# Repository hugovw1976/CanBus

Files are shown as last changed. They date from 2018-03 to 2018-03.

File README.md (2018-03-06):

# CanBus
Wireless Control CanBus Electrical System for 1976 VW Bug.
NRF24L01 With ATmega328p Wireless control for car electrical system.
Transmitter run on ATmega 328p running on low power mode 1mhz: https://forum.mysensors.org/topic/3018/tutorial-how-to-burn-1mhz-8mhz-bootloader-using-arduino-ide-1-6-5-r5/2
Receiver run on Teensy 3.2 with SN65HVD230 transceiver, module communicate with front/rear/midle modules over CanBus
CanBus Modules run on Teensy 3.2 with SN65HVD230 transceiver.
Wiper control over LinBus (motor from BMW) LIN library from: https://github.com/gandrewstone/LIN/blob/master/LIN.ino
  
  Transmitter:







<a data-flickr-embed="true" data-context="true"  href="https://www.flickr.com/photos/r42bug/39444284152/in/dateposted/" title="20171224_134232">

Receiver:



Can modules:





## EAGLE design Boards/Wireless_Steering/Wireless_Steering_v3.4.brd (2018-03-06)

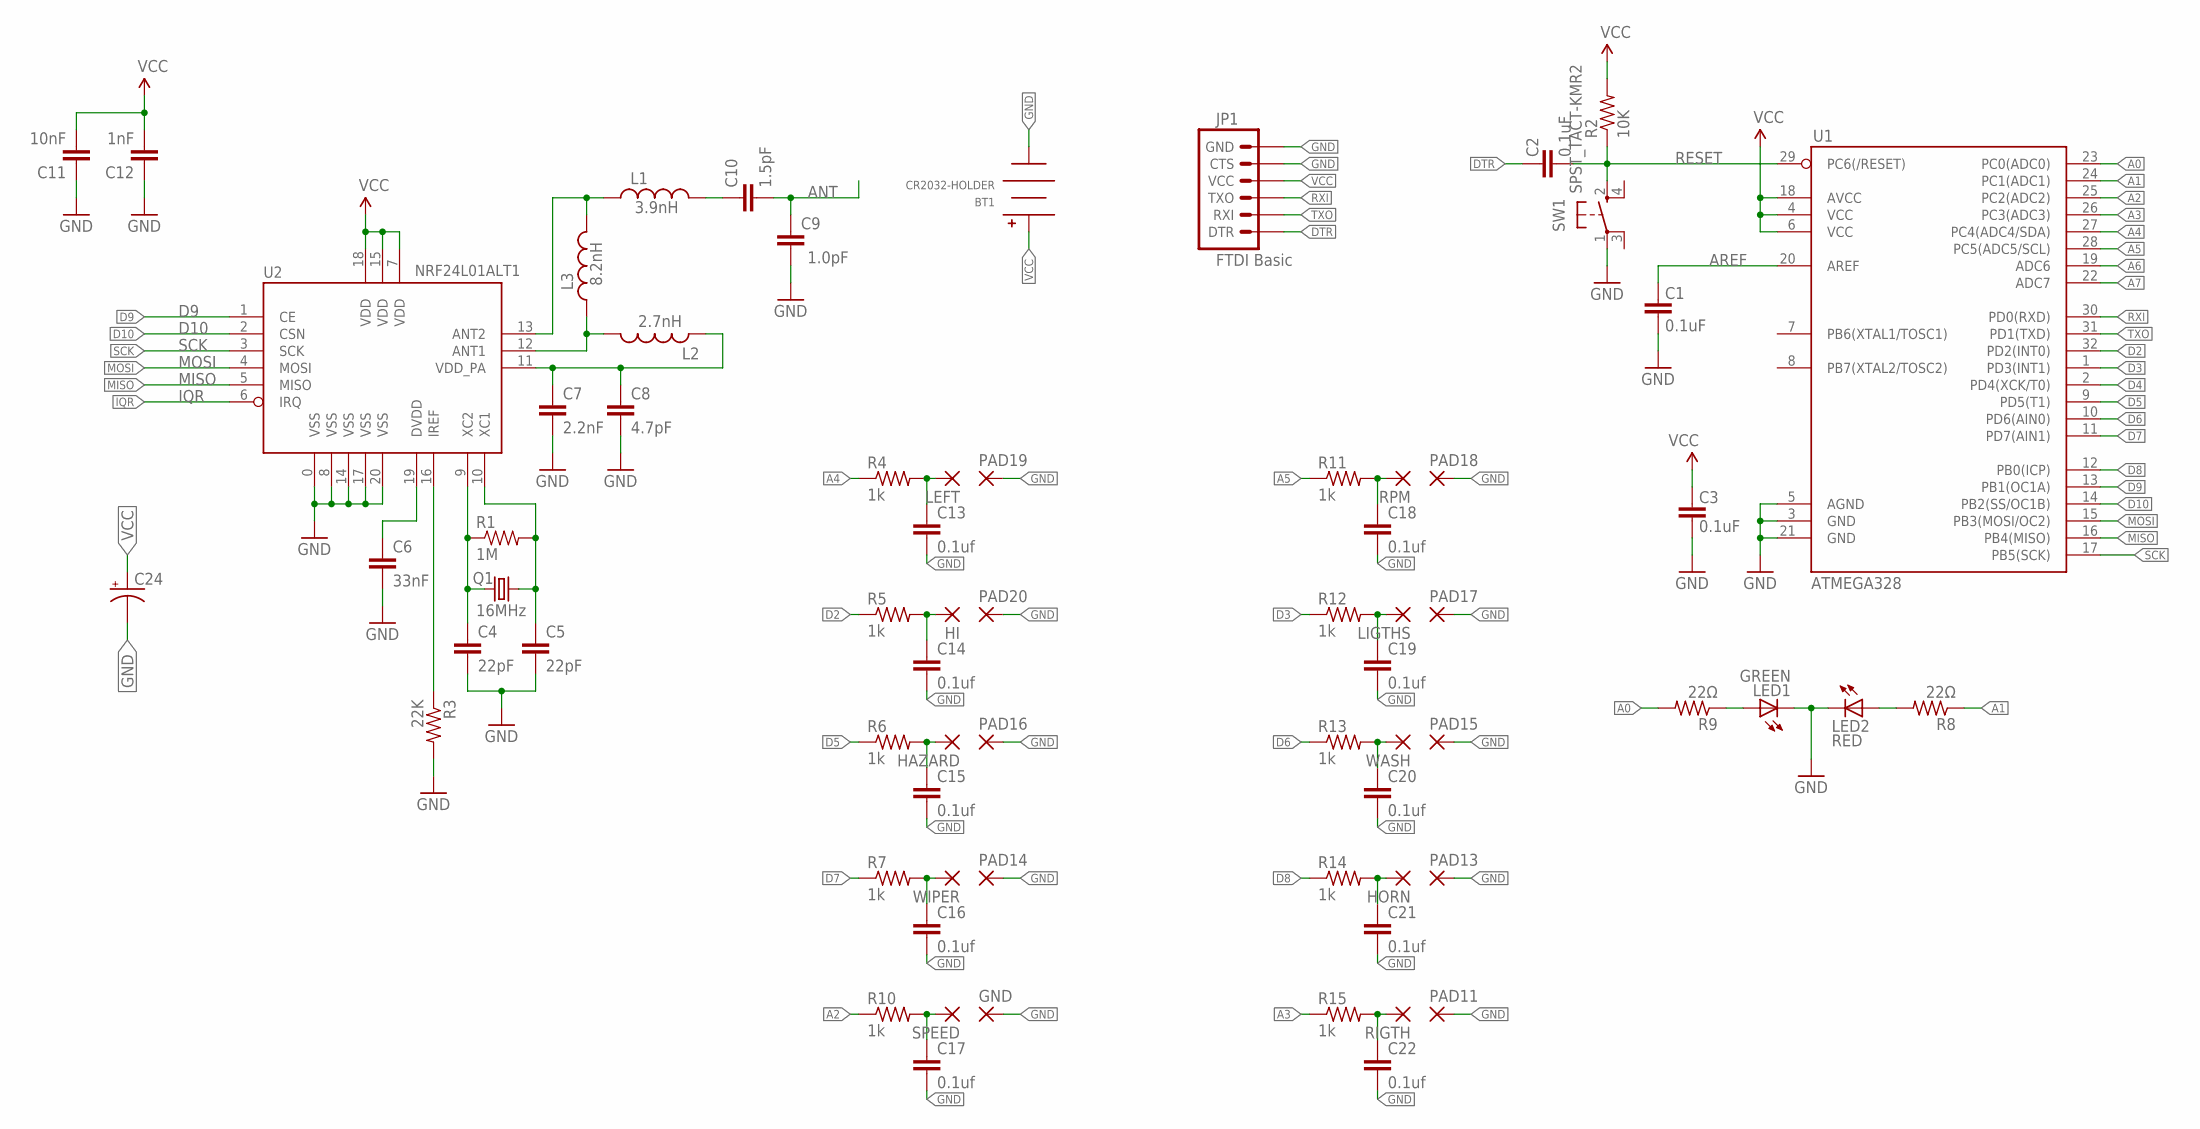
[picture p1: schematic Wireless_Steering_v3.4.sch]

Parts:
BT1: CR2032-HOLDER; CH28-2032LF
C1, C2, C3: 0.1uF; 0402-CAP
C4, C5: 22pF; 0402-CAP
C6: 33nF; 0402-CAP
C7: 2.2nF; 0402-CAP
C8: 4.7pF; 0402-CAP
C9: 1.0pF; 0402-CAP
C10: 1.5pF; 0402-CAP
C11: 10nF; 0402-CAP
C12: 1nF; 0402-CAP
C13, C14, C15, C16, C17, C18, C19, C20, C21, C22: 0.1uf; 0402-CAP
C24: CAP_POL1206; EIA3216
GND: SMD2; SMD1,27-2,54
HAZARD: SMD2; SMD1,27-2,54
HI: SMD2; SMD1,27-2,54
HORN: SMD2; SMD1,27-2,54
JP1: FTDI Basic; 1X06
L1: 3.9nH; C0402
L2: 2.7nH; C0402
L3: 8.2nH; C0402
LED1: GREEN; CHIP-LED0603
LED2: RED; CHIP-LED0603
LEFT: SMD2; SMD1,27-2,54
LIGTHS: SMD2; SMD1,27-2,54
PAD11, PAD13, PAD14, PAD15, PAD16, PAD17, PAD18, PAD19, PAD20: SMD2; SMD1,27-2,54
Q1: 16MHz; CRYSTAL-SMD-5X3
R1: 1M; 0402-RES
R2: 10K; 0402-RES
R3: 22K; 0402-RES
R4, R5, R6, R7, R10, R11, R12, R13, R14, R15: 1k; R0402
R8, R9: 22Ω; R0402
RIGTH: SMD2; SMD1,27-2,54
RPM: SMD2; SMD1,27-2,54
SPEED: SMD2; SMD1,27-2,54
SW1: SPST_TACT-KMR2; KMR2
U1: ATMEGA328; TQFP32-08
U2: NRF24L01ALT1; QFN20_ALT1
WASH: SMD2; SMD1,27-2,54
WIPER: SMD2; SMD1,27-2,54

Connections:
A0: R9.2, U1.23 (PC0(ADC0))
A1: R8.1, U1.24 (PC1(ADC1))
A2: R10.1, U1.25 (PC2(ADC2))
A3: R15.1, U1.26 (PC3(ADC3))
A4: R4.1, U1.27 (PC4(ADC4/SDA))
A5: R11.1, U1.28 (PC5(ADC5/SCL))
A6: U1.19 (ADC6)
A7: U1.22 (ADC7)
ANT: C9.2, C10.2
AREF: C1.2, U1.20 (AREF)
D2: R5.1, U1.32 (PD2(INT0))
D3: R12.1, U1.1 (PD3(INT1))
D4: U1.2 (PD4(XCK/T0))
D5: R6.1, U1.9 (PD5(T1))
D6: R13.1, U1.10 (PD6(AIN0))
D7: R7.1, U1.11 (PD7(AIN1))
D8: R14.1, U1.12 (PB0(ICP))
D9: U1.13 (PB1(OC1A)), U2.1 (CE)
D10: U1.14 (PB2(SS/OC1B)), U2.2 (CSN)
DTR: C2.2, JP1.1 (DTR)
GND: BT1.NEG, C1.1, C3.1, C4.2, C5.2, C6.2, C7.2, C8.2, C9.1, C11.1, C12.1, C13.2, C14.2, C15.2, C16.2, C17.2, C18.2, C19.2, C20.2, C21.2, C22.2, C24.C (-), GND.1, JP1.5 (CTS), JP1.6 (GND), LED1.C, LED2.C, PAD11.1, PAD13.1, PAD14.1, PAD15.1, PAD16.1, PAD17.1, PAD18.1, PAD19.1, PAD20.1, R3.2, SW1.1, U1.3 (GND), U1.5 (AGND), U1.21 (GND), U2.0 (VSS), U2.8 (VSS), U2.14 (VSS), U2.17 (VSS), U2.20 (VSS)
IQR: U2.6 (IRQ)
MISO: U1.16 (PB4(MISO)), U2.5 (MISO)
MOSI: U1.15 (PB3(MOSI/OC2)), U2.4 (MOSI)
unnamed: C4.1, Q1.1, R1.1, U2.9 (XC2)
unnamed: C5.1, Q1.3 (2), R1.2, U2.10 (XC1)
unnamed: L1.1, L3.2, U2.13 (ANT2)
unnamed: LED2.A, R8.2
unnamed: LED1.A, R9.1
unnamed: C7.1, C8.1, L2.1, U2.11 (VDD_PA)
unnamed: R3.1, U2.16 (IREF)
unnamed: C6.1, U2.19 (DVDD)
unnamed: L2.2, L3.1, U2.12 (ANT1)
unnamed: C10.1, L1.2
unnamed: C13.1, LEFT.1, R4.2
unnamed: C14.1, HI.1, R5.2
unnamed: C16.1, R7.2, WIPER.1
unnamed: C17.1, R10.2, SPEED.1
unnamed: C22.1, R15.2, RIGTH.1
unnamed: C21.1, HORN.1, R14.2
unnamed: C20.1, R13.2, WASH.1
unnamed: C19.1, LIGTHS.1, R12.2
unnamed: C18.1, R11.2, RPM.1
unnamed: C15.1, HAZARD.1, R6.2
RESET: C2.1, R2.1, SW1.2 (S), U1.29 (PC6(/RESET))
RXI: JP1.3 (TXO), U1.30 (PD0(RXD))
SCK: U1.17 (PB5(SCK)), U2.3 (SCK)
TXO: JP1.2 (RXI), U1.31 (PD1(TXD))
VCC: BT1.POS, C3.2, C11.2, C12.2, C24.A (+), JP1.4 (VCC), R2.2, U1.4 (VCC), U1.6 (VCC), U1.18 (AVCC), U2.7 (VDD), U2.15 (VDD), U2.18 (VDD)

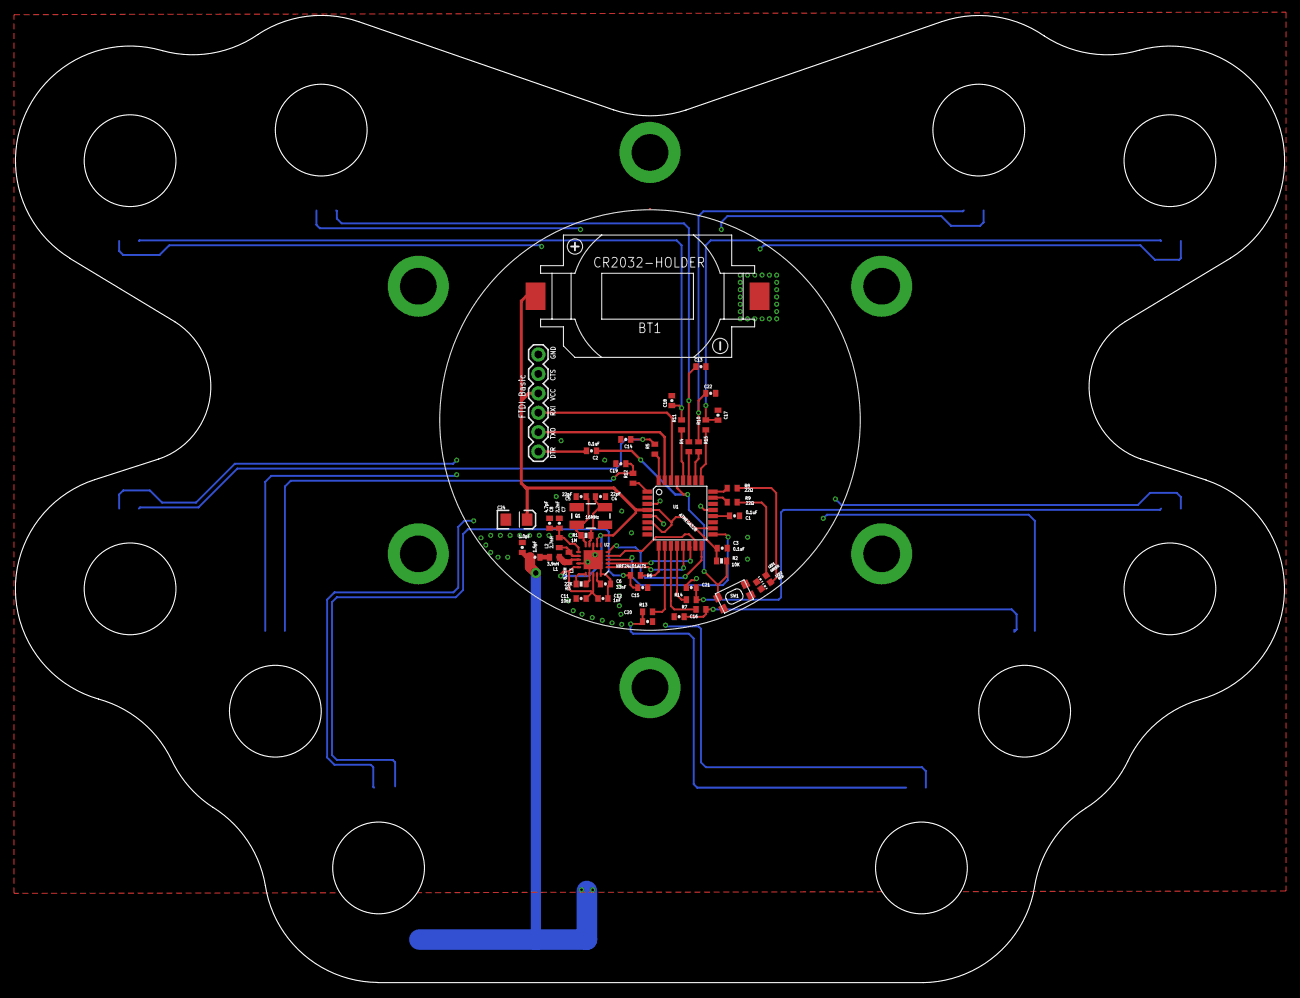
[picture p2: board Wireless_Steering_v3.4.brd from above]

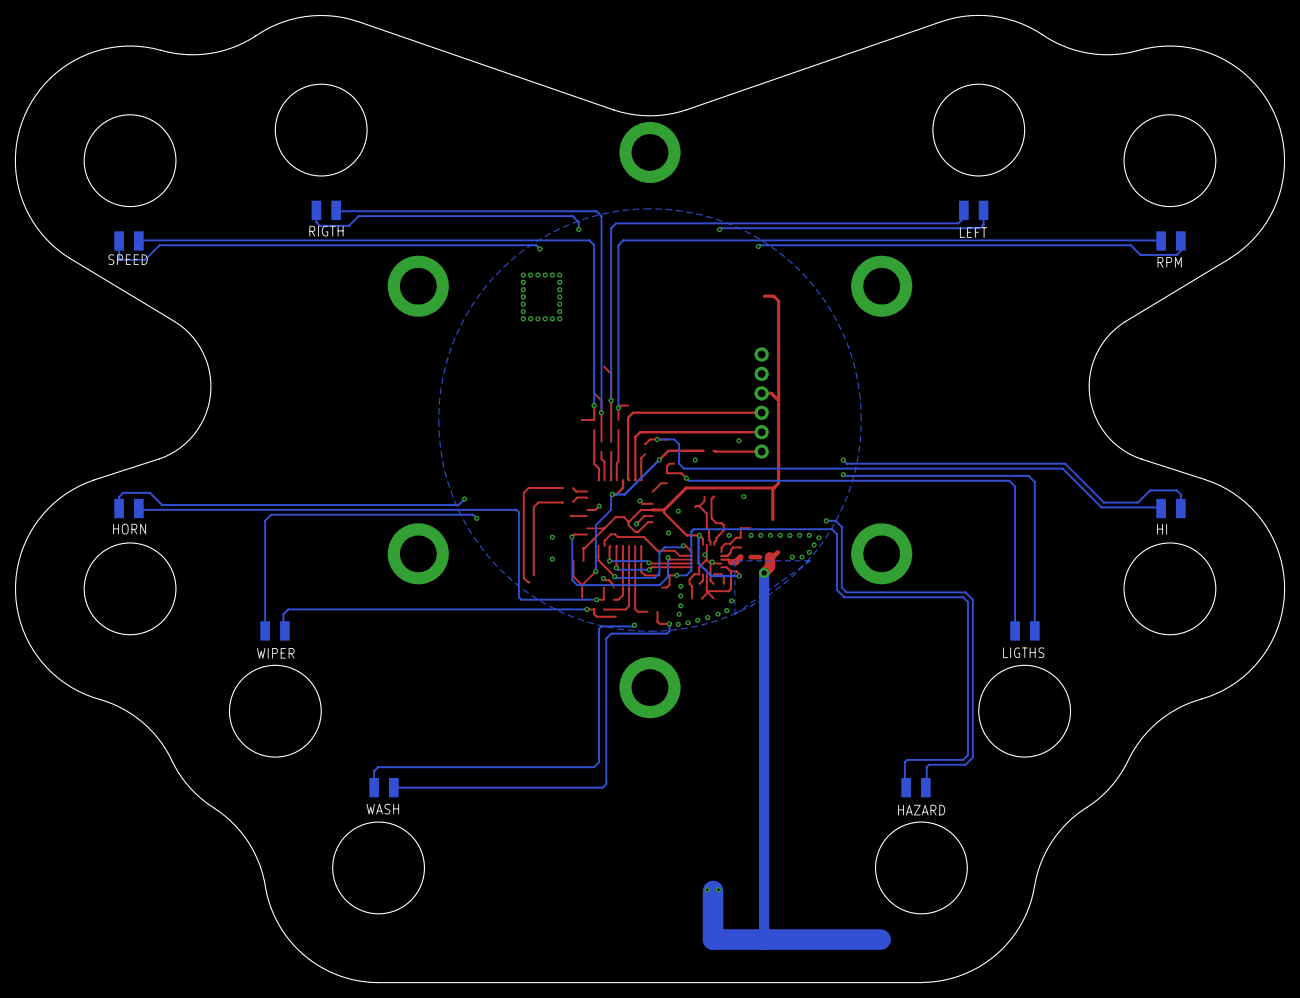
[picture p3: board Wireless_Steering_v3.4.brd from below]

Board: 2 copper layers, 166.0 x 126.5 mm, 69 parts (20 on the bottom side), 45 nets.

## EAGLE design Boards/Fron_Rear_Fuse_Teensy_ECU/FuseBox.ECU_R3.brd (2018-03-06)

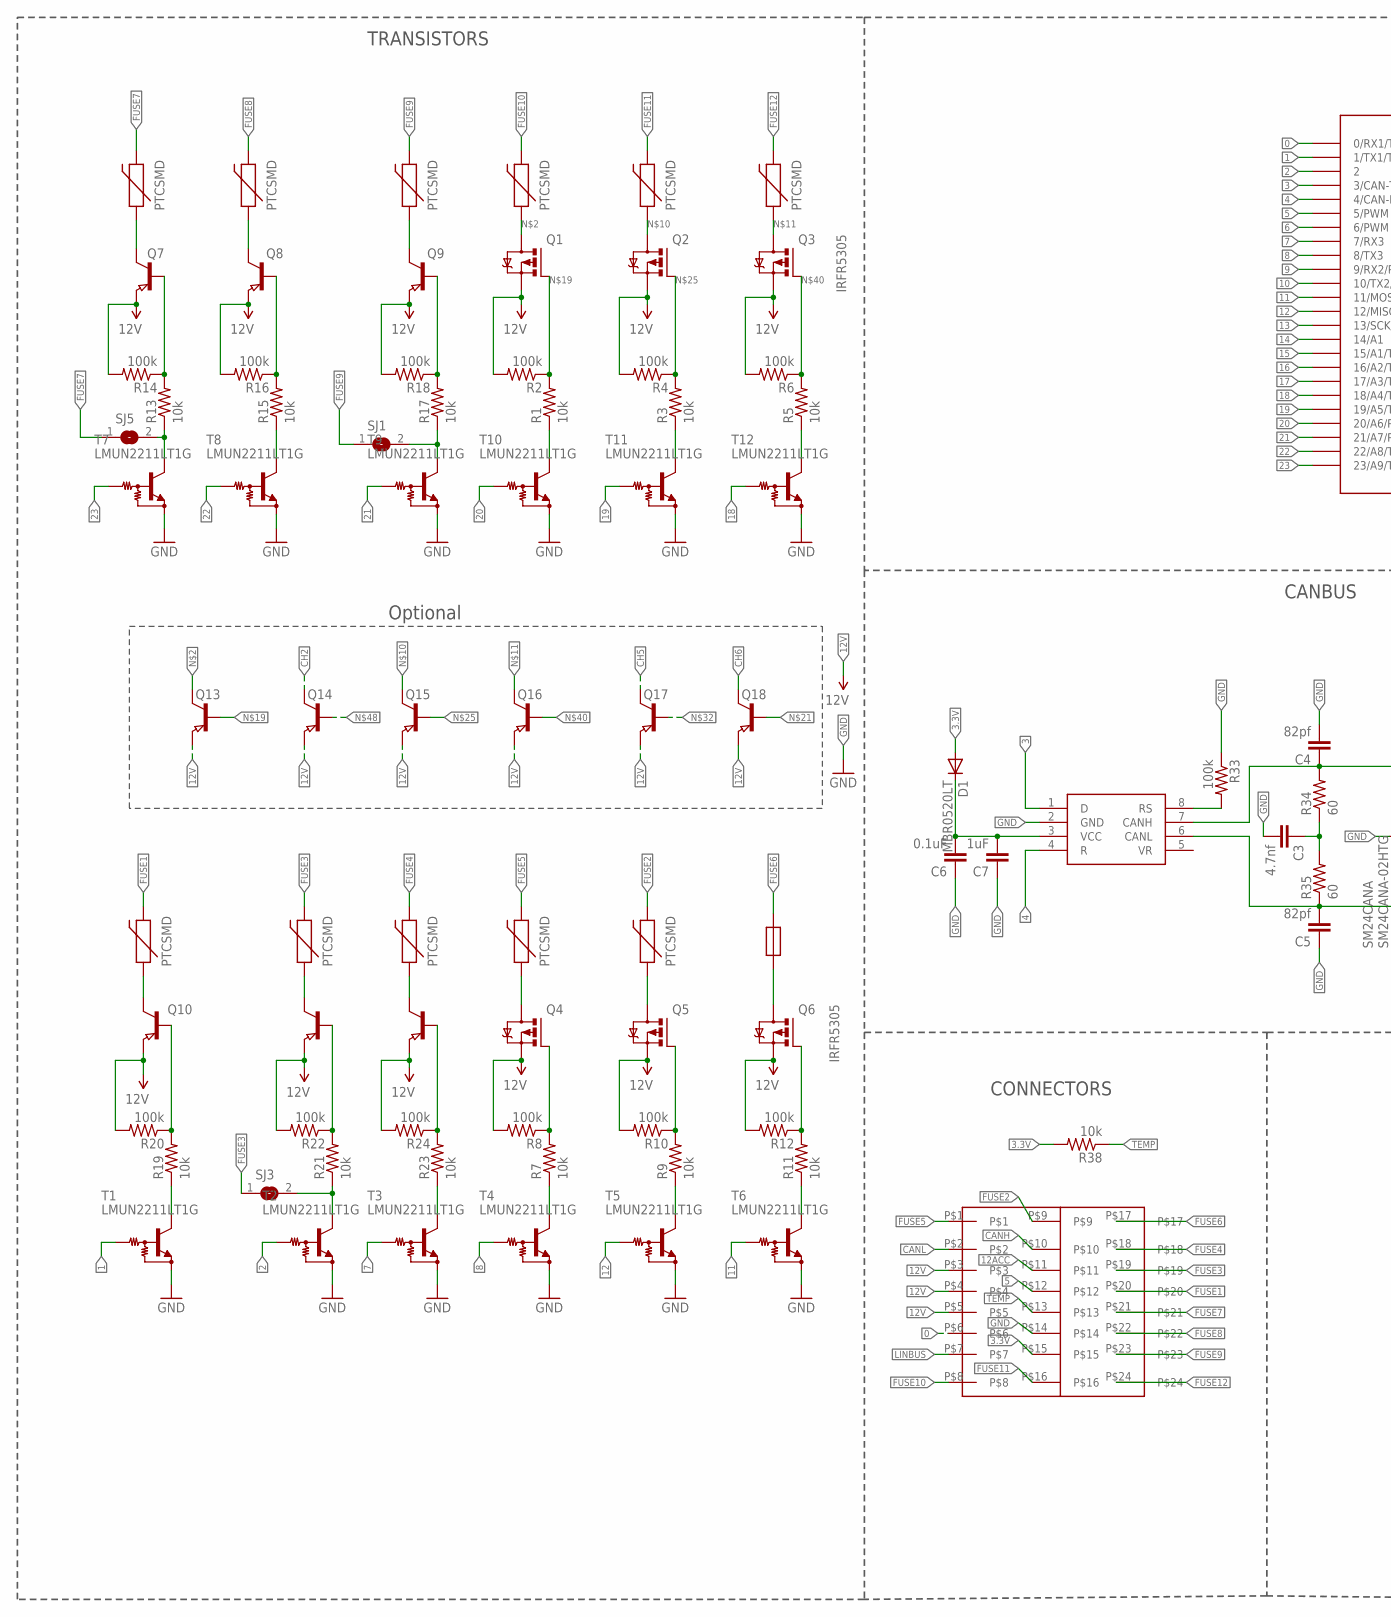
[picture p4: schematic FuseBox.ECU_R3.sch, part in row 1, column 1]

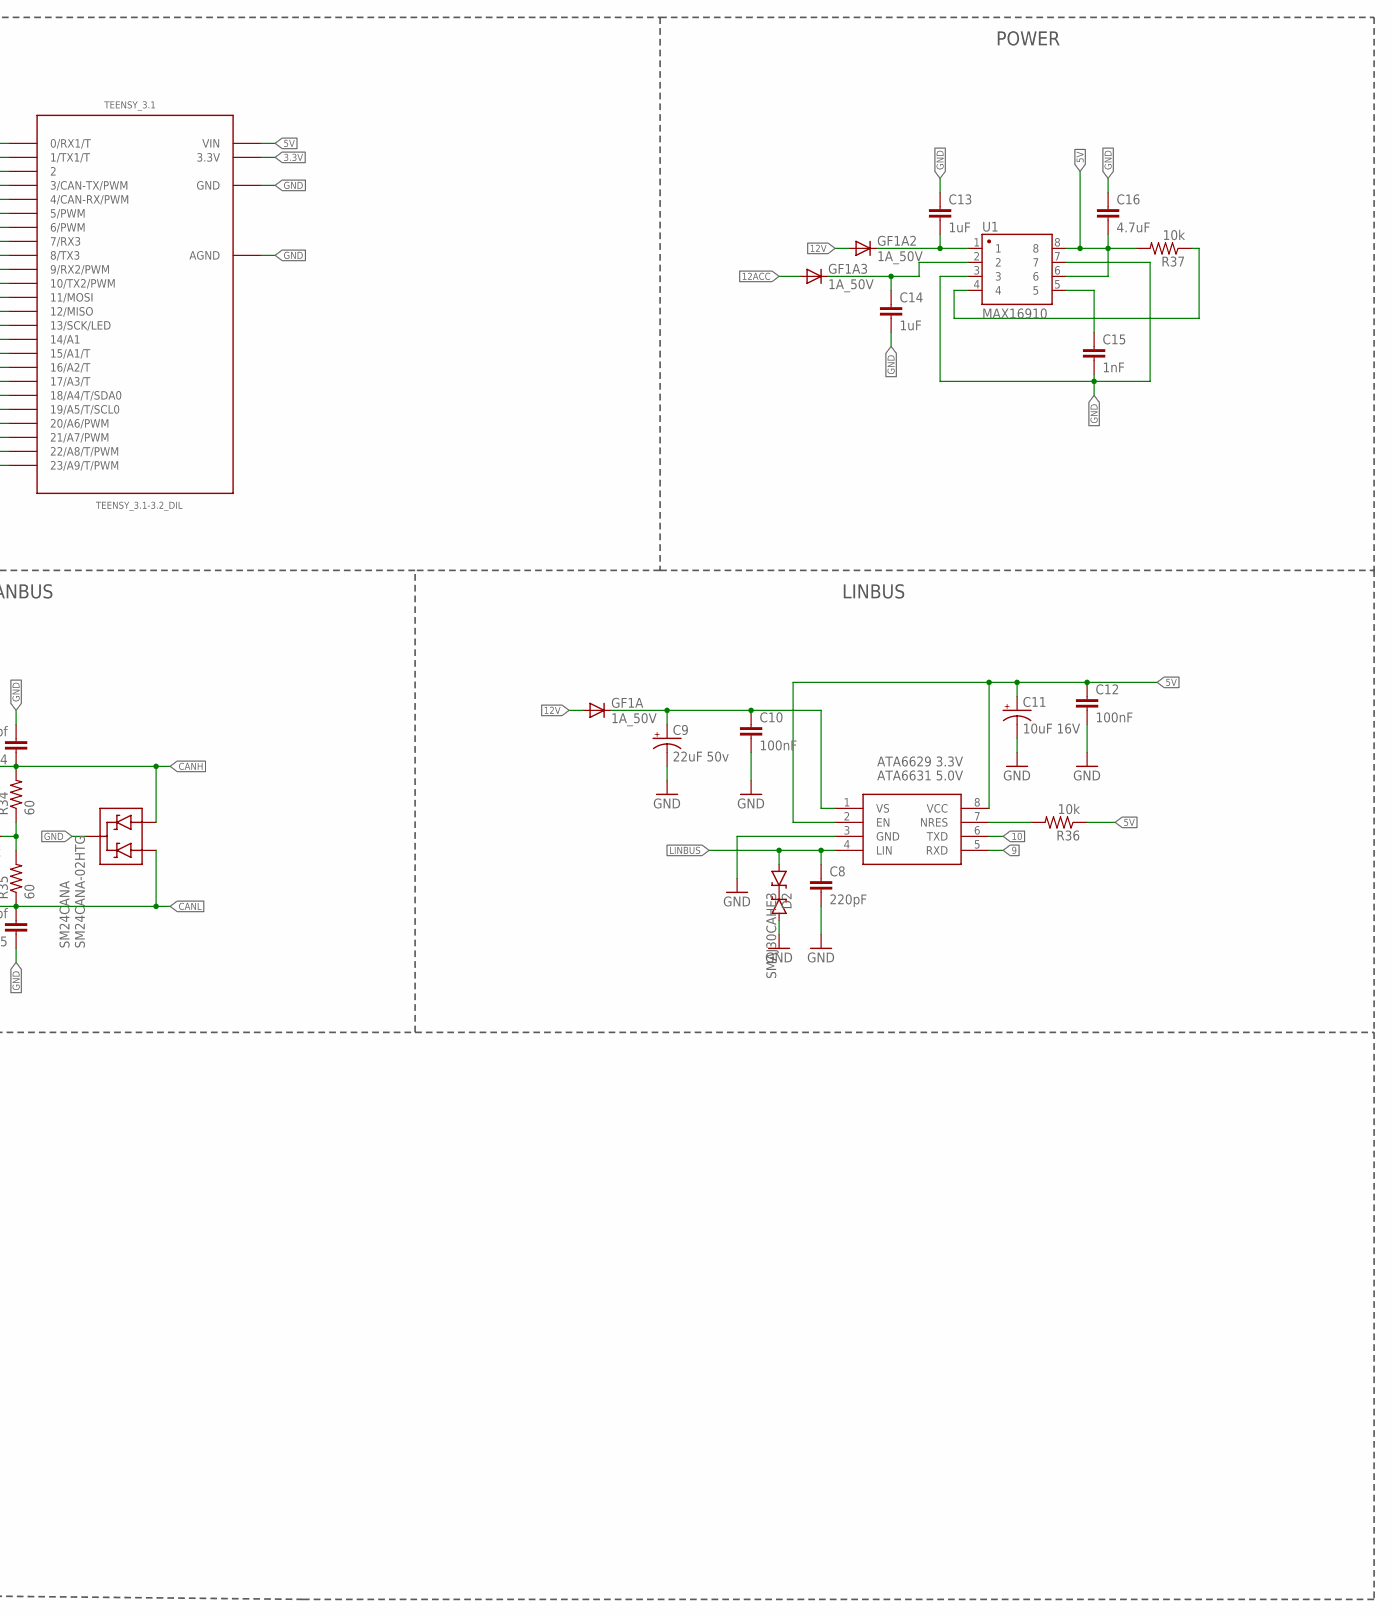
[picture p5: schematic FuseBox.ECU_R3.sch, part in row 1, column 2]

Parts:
ATA6631: ATA6631; S08
C3: 4.7nf; 0603-CAP
C4, C5: 82pf; 0603-CAP
C6: 0.1uF; 0603-CAP
C7: 1uF; 0603-CAP
C8: 220pF; 0603-CAP
C9: 22uF 50v; PANASONIC_D
C10, C12: 100nF; 0603-CAP
C11: 10uF 16V; EIA3216
C13, C14: 1uF; 0805
C15: 1nF; 0805
C16: 4.7uF; 0805
D1: MBR0520LT; SOD123
D2: SMAJ30CAHE3; SMA-DIODE
F1, F2, F3, F4, F5, F6, F7, F8, F9, F10, F11: PTCSMD; PTC-1206
GF1A, GF1A2, GF1A3: 1A_50V; DO-214AC
Q1, Q2, Q3, Q4, Q5, Q6: IRFR5305; D-PAK_TO252AA
Q7, Q8, Q9, Q10, Q11, Q12, Q13, Q14, Q15, Q16, Q17, Q18: PNP-TRANSISTOR_SOT23; SOT23
R1, R3, R5, R7, R9, R11, R13, R15, R17, R19, R21, R23, R38: 10k; R0402
R2, R4, R6, R8, R10, R12, R14, R16, R18, R20, R22, R24, R33: 100k; R0402
R34, R35: 60; R0402
R36, R37: 10k; 0603-RES
SJ1, SJ3, SJ5: SJ
SM24CANA: SM24CANA-02HTG; SOT23-3
T1, T2, T3, T4, T5, T6, T7, T8, T9, T10, T11, T12: LMUN2211LT1G; SOT23
TEENSY_3.1: TEENSY_3.1-3.2_DIL; TEENSY_3.0-3.2&LC_DIL
U1: MAX16910; SO08
U$2: RESETTABLE_1210; 1210
U$3: HCCPHPE24BKA90F
VP230: UP230; SO08

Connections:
0: TEENSY_3.1.0 (0/RX1/T), U$3.P$6
1: T1.1 (B), TEENSY_3.1.1 (1/TX1/T)
2: T2.1 (B), TEENSY_3.1.2
3: TEENSY_3.1.3 (3/CAN-TX/PWM), VP230.1 (D)
3.3V: D1.A, R38.2, TEENSY_3.1.3.3V, U$3.P$15
4: TEENSY_3.1.4 (4/CAN-RX/PWM), VP230.4 (R)
5: TEENSY_3.1.5 (5/PWM), U$3.P$12
5V: ATA6631.2 (EN), ATA6631.8 (VCC), C11.A (+), C12.1, C16.2, R36.1, R37.2, TEENSY_3.1.VIN, U1.6, U1.8
6: TEENSY_3.1.6 (6/PWM)
7: T3.1 (B), TEENSY_3.1.7 (7/RX3)
8: T4.1 (B), TEENSY_3.1.8 (8/TX3)
9: ATA6631.5 (RXD), TEENSY_3.1.9 (9/RX2/PWM)
10: ATA6631.6 (TXD), TEENSY_3.1.10 (10/TX2/PWM)
11: T6.1 (B), TEENSY_3.1.11 (11/MOSI)
12: T5.1 (B), TEENSY_3.1.12 (12/MISO)
12ACC: GF1A3.A, U$3.P$11
12V: GF1A.A, GF1A2.A, Q1.3 (S), Q2.3 (S), Q3.3 (S), Q4.3 (S), Q5.3 (S), Q6.3 (S), Q7.2 (E), Q8.2 (E), Q9.2 (E), Q10.2 (E), Q11.2 (E), Q12.2 (E), Q13.2 (E), Q14.2 (E), Q15.2 (E), Q16.2 (E), Q17.2 (E), Q18.2 (E), R2.2, R4.2, R6.2, R8.2, R10.2, R12.2, R14.2, R16.2, R18.2, R20.2, R22.2, R24.2, U$3.P$3, U$3.P$4, U$3.P$5
13: TEENSY_3.1.13 (13/SCK/LED)
14: TEENSY_3.1.14/A0 (14/A1)
15: TEENSY_3.1.15/A1 (15/A1/T)
16: TEENSY_3.1.16/A2 (16/A2/T)
17: TEENSY_3.1.17/A3 (17/A3/T)
18: T12.1 (B), TEENSY_3.1.18/A4 (18/A4/T/SDA0)
19: T11.1 (B), TEENSY_3.1.19/A5 (19/A5/T/SCL0)
20: T10.1 (B), TEENSY_3.1.20/A6 (20/A6/PWM)
21: T9.1 (B), TEENSY_3.1.21/A7 (21/A7/PWM)
22: T8.1 (B), TEENSY_3.1.22/A8 (22/A8/T/PWM)
23: T7.1 (B), TEENSY_3.1.23/A9 (23/A9/T/PWM)
CANH: C4.1, R34.2, SM24CANA.2 (A2), U$3.P$10, VP230.7 (CANH)
CANL: C5.2, R35.1, SM24CANA.1 (A1), U$3.P$2, VP230.6 (CANL)
CH2: F1.1, Q5.4 (D), Q14.3 (C)
CH5: F2.1, Q4.4 (D), Q17.3 (C)
CH6: Q6.4 (D), Q18.3 (C), U$2.P$1
CH7: F6.1, Q7.3 (C)
CH8: F7.1, Q8.3 (C)
CH9: F8.1, Q9.3 (C)
FUSE1: F5.2, U$3.P$20
FUSE2: F1.2, U$3.P$9
FUSE3: F4.2, SJ3.1, U$3.P$19
FUSE4: F3.2, U$3.P$18
FUSE5: F2.2, U$3.P$1
FUSE6: U$2.P$2, U$3.P$17
FUSE7: F6.2, SJ5.1, U$3.P$21
FUSE8: F7.2, U$3.P$22
FUSE9: F8.2, SJ1.1, U$3.P$23
FUSE10: F9.2, U$3.P$8
FUSE11: F10.2, U$3.P$16
FUSE12: F11.2, U$3.P$24
GND: ATA6631.3 (GND), C3.2, C4.2, C5.1, C6.1, C7.1, C8.2, C9.-, C10.2, C11.C (-), C12.2, C13.1, C14.2, C15.2, C16.1, D2.A, R33.1, SM24CANA.3 (C), T1.2 (E), T2.2 (E), T3.2 (E), T4.2 (E), T5.2 (E), T6.2 (E), T7.2 (E), T8.2 (E), T9.2 (E), T10.2 (E), T11.2 (E), T12.2 (E), TEENSY_3.1.AGND, TEENSY_3.1.GND, U1.3, U1.7, U$3.P$14, VP230.2 (GND)
LINBUS: ATA6631.4 (LIN), C8.1, D2.C (A1), U$3.P$7
unnamed: C6.2, C7.2, D1.C, VP230.3 (VCC)
unnamed: F9.1, Q1.4 (D), Q13.3 (C)
unnamed: R15.1, T8.3 (C)
unnamed: Q8.1 (B), R15.2, R16.1
unnamed: R13.1, SJ5.2, T7.3 (C)
unnamed: Q7.1 (B), R13.2, R14.1
unnamed: C13.2, GF1A2.C, U1.1
unnamed: R17.1, SJ1.2, T9.3 (C)
unnamed: F10.1, Q2.4 (D), Q15.3 (C)
unnamed: F11.1, Q3.4 (D), Q16.3 (C)
unnamed: C14.1, GF1A3.C, U1.2
unnamed: Q9.1 (B), R17.2, R18.1
unnamed: R1.1, T10.3 (C)
unnamed: Q1.1 (G), Q13.1 (B), R1.2, R2.1
unnamed: R11.1, T6.3 (C)
unnamed: Q6.1 (G), Q18.1 (B), R11.2, R12.1
unnamed: F5.1, Q10.3 (C)
unnamed: F4.1, Q11.3 (C)
unnamed: R3.1, T11.3 (C)
unnamed: Q2.1 (G), Q15.1 (B), R3.2, R4.1
unnamed: F3.1, Q12.3 (C)
unnamed: R23.1, T3.3 (C)
unnamed: Q12.1 (B), R23.2, R24.1
unnamed: R37.1, U1.4
unnamed: R7.1, T4.3 (C)
unnamed: Q4.1 (G), Q17.1 (B), R7.2, R8.1
unnamed: C15.1, U1.5
unnamed: R5.1, T12.3 (C)
unnamed: Q3.1 (G), Q16.1 (B), R5.2, R6.1
unnamed: R21.1, SJ3.2, T2.3 (C)
unnamed: Q11.1 (B), R21.2, R22.1
unnamed: R19.1, T1.3 (C)
unnamed: Q10.1 (B), R19.2, R20.1
unnamed: R9.1, T5.3 (C)
unnamed: Q5.1 (G), Q14.1 (B), R9.2, R10.1
unnamed: R33.2, VP230.8 (RS)
unnamed: ATA6631.1 (VS), C9.+, C10.1, GF1A.C
unnamed: ATA6631.7 (NRES), R36.2
unnamed: C3.1, R34.1, R35.2
TEMP: R38.1, U$3.P$13

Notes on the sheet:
ATA6631 5.0V
ATA6629 3.3V
Optional
TRANSISTORS
POWER
CANBUS
LINBUS
CONNECTORS

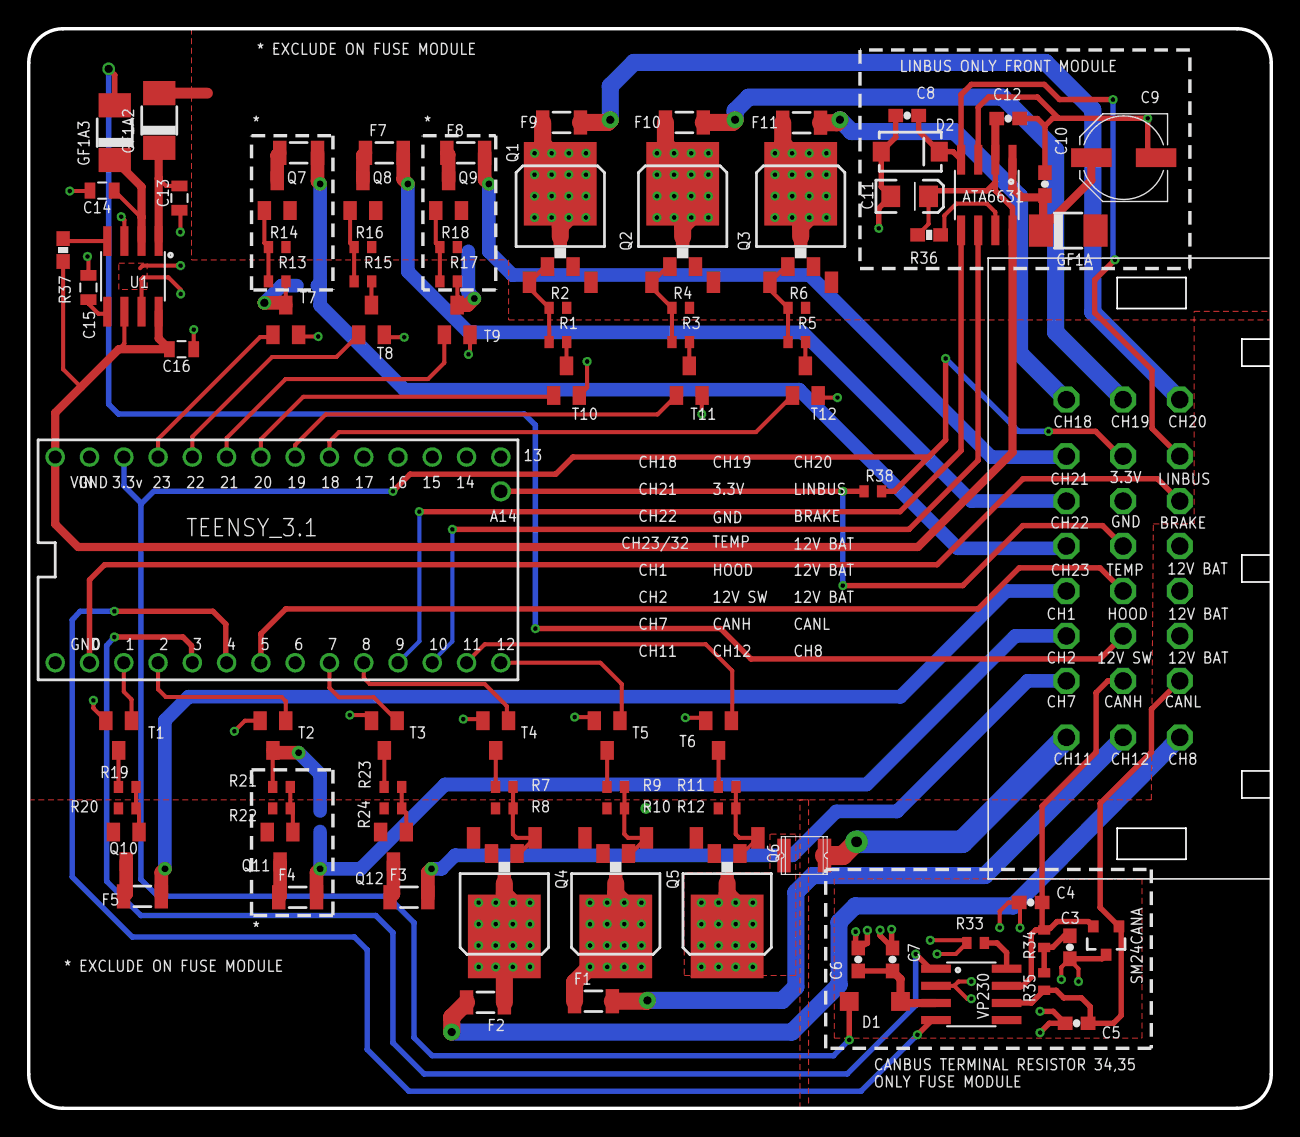
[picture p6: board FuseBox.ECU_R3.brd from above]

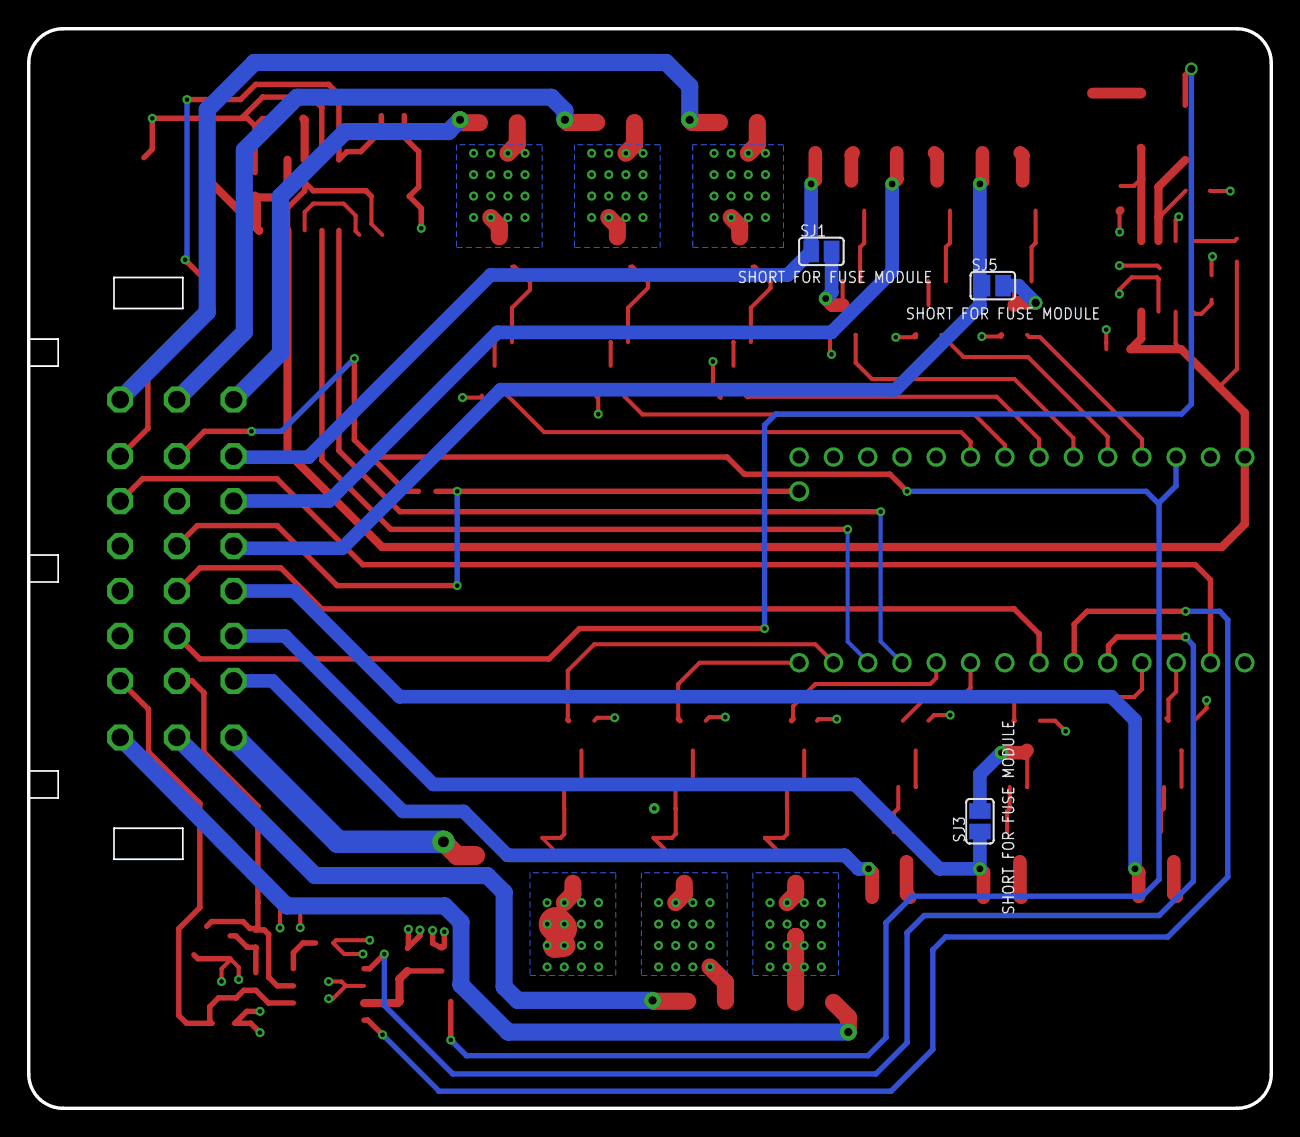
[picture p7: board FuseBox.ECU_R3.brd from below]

Board: 2 copper layers, 92.1 x 80.0 mm, 100 parts (3 on the bottom side), 84 nets.

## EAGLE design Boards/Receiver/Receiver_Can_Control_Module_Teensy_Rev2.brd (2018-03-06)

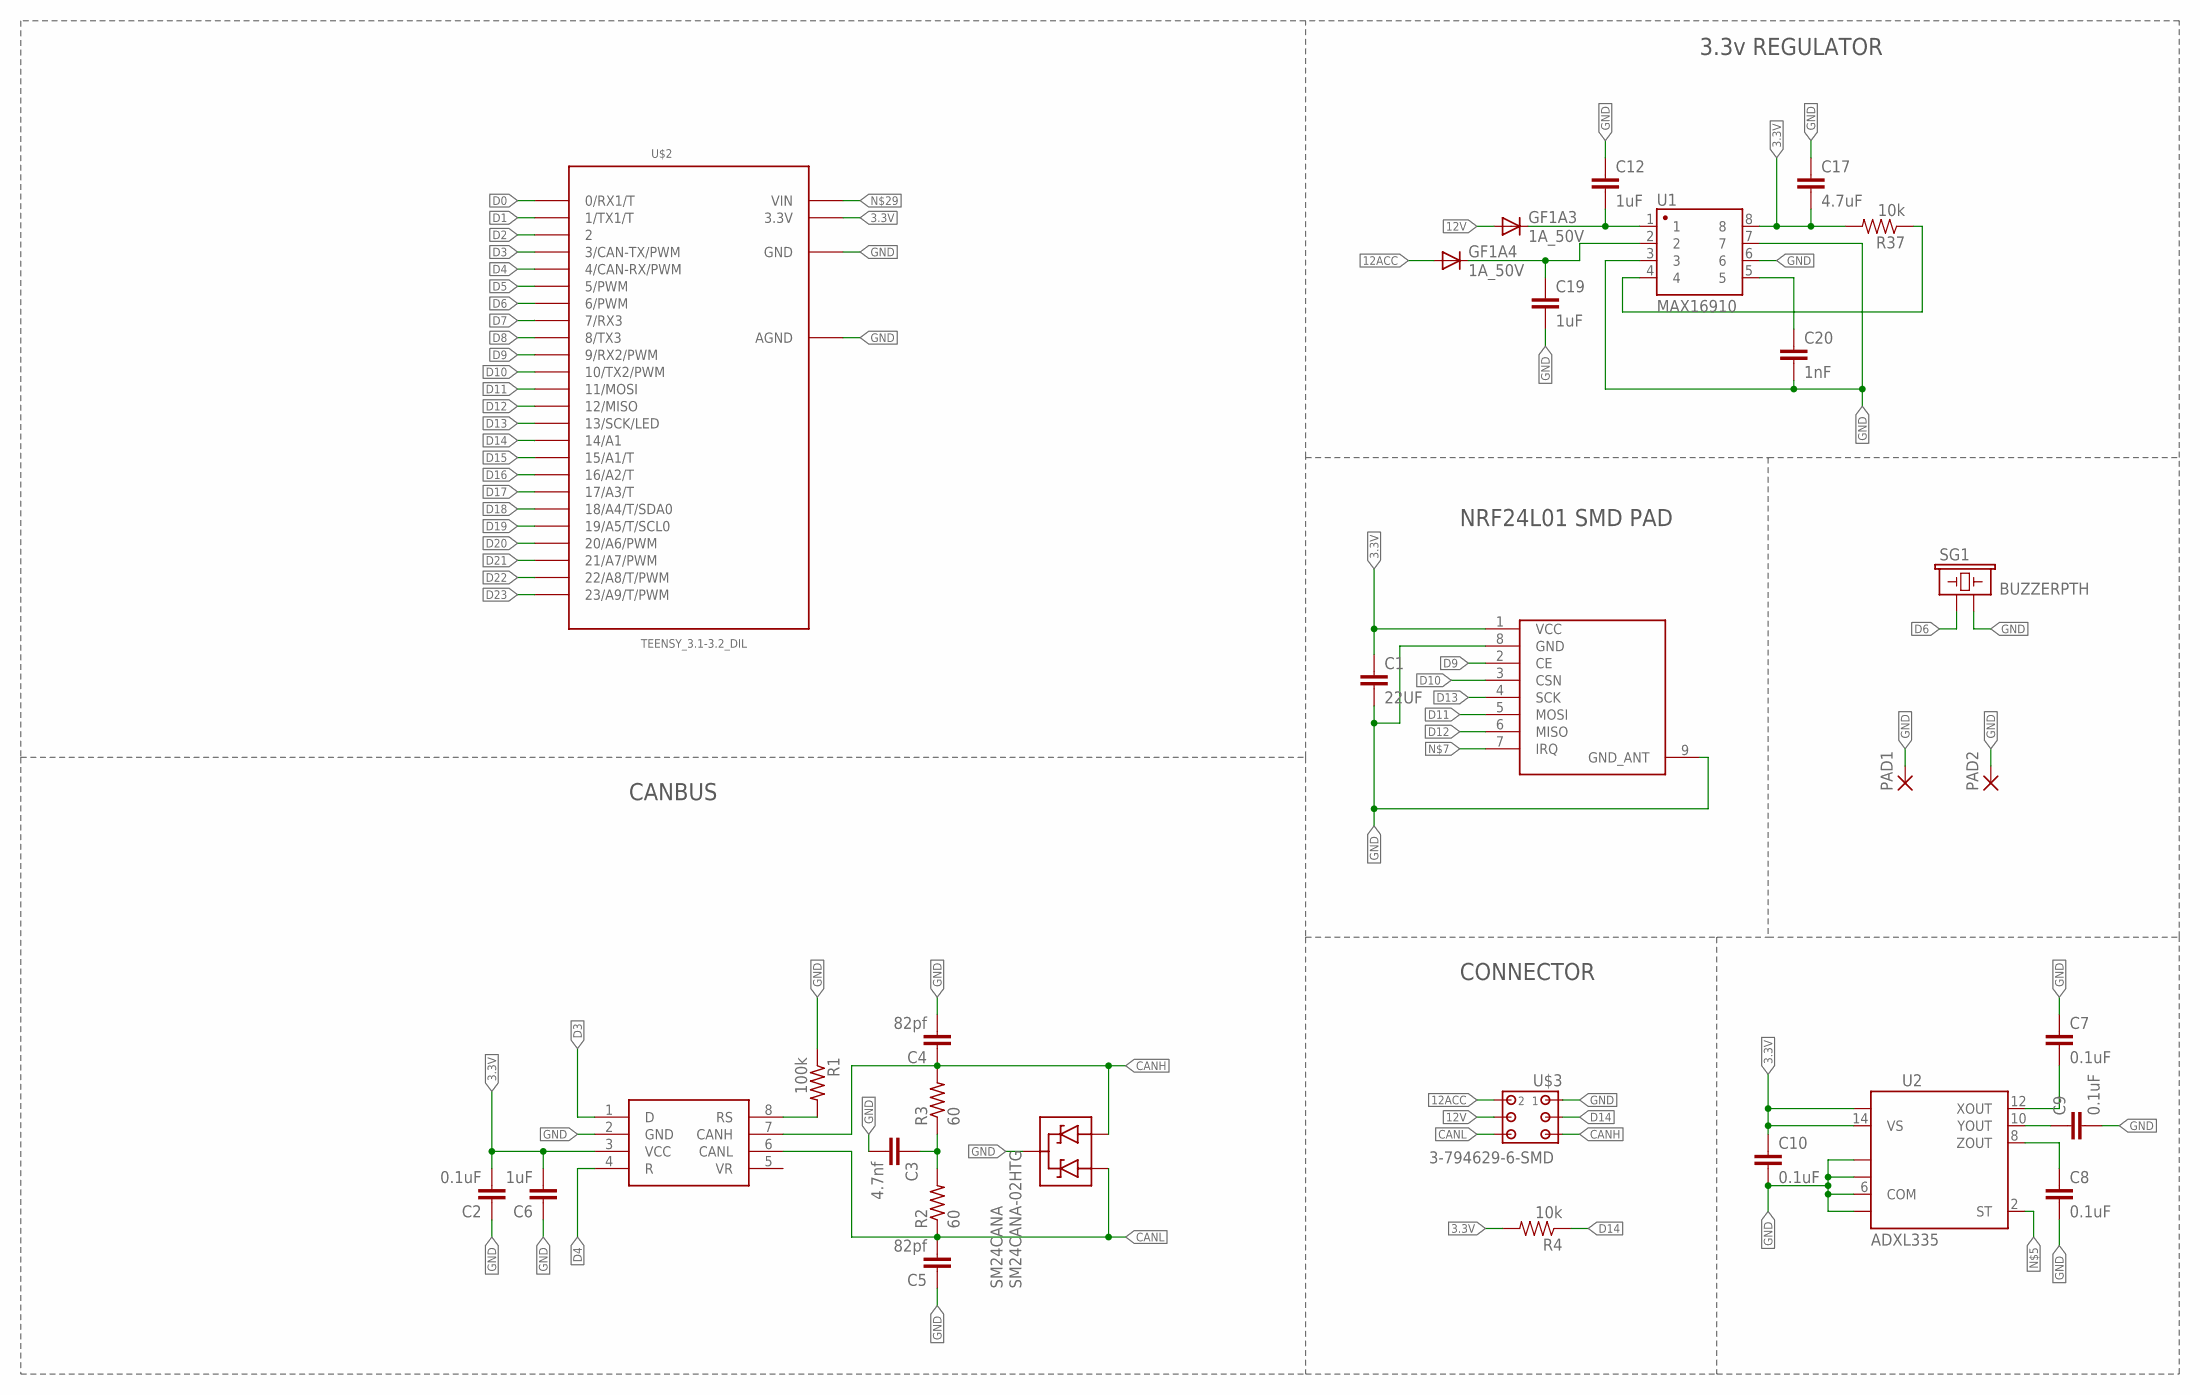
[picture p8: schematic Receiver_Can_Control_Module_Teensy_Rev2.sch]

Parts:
C1: 22UF; 1206
C2, C7, C8, C9, C10: 0.1uF; 0603-CAP
C3: 4.7nf; 0603-CAP
C4, C5: 82pf; 0603-CAP
C6: 1uF; 0603-CAP
C12, C19: 1uF; 0805
C17: 4.7uF; 0805
C20: 1nF; 0805
GF1A3, GF1A4: 1A_50V; DO-214AC
PAD1, PAD2: SMD2; SMD1,27-2,54
R1: 100k; R0402
R2, R3: 60; R0402
R4, R37: 10k; 0603-RES
SG1: BUZZERPTH; BUZZER-12MM
SM24CANA: SM24CANA-02HTG; SOT23-3
U1: MAX16910; SO08
U2: ADXL335; LFCSP-16
U$1: NRF24L01_PAD2; NRF24-2
U$2: TEENSY_3.1-3.2_DIL; TEENSY_3.0-3.2&LC_DIL
U$3: 3-794629-6-SMD; 3-794629-6
VP230: UP230; SO08

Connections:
3.3V: C1.1, C2.2, C6.2, C10.1, C17.2, R4.2, R37.2, U1.8, U2.14 (VS), U2.15 (VS), U$1.1 (VCC), U$2.3.3V, VP230.3 (VCC)
12ACC: GF1A4.A, U$3.2
12V: GF1A3.A, U$3.4
CANH: C4.1, R3.2, SM24CANA.2 (A2), U$3.5, VP230.7 (CANH)
CANL: C5.2, R2.1, SM24CANA.1 (A1), U$3.6, VP230.6 (CANL)
D0: U$2.0 (0/RX1/T)
D1: U$2.1 (1/TX1/T)
D2: U$2.2
D3: U$2.3 (3/CAN-TX/PWM), VP230.1 (D)
D4: U$2.4 (4/CAN-RX/PWM), VP230.4 (R)
D5: U$2.5 (5/PWM)
D6: SG1.+ (1), U$2.6 (6/PWM)
D7: U$2.7 (7/RX3)
D8: U$2.8 (8/TX3)
D9: U$1.2 (CE), U$2.9 (9/RX2/PWM)
D10: U$1.3 (CSN), U$2.10 (10/TX2/PWM)
D11: U$1.5 (MOSI), U$2.11 (11/MOSI)
D12: U$1.6 (MISO), U$2.12 (12/MISO)
D13: U$1.4 (SCK), U$2.13 (13/SCK/LED)
D14: R4.1, U$2.14/A0 (14/A1), U$3.3
D15: U$2.15/A1 (15/A1/T)
D16: U$2.16/A2 (16/A2/T)
D17: U$2.17/A3 (17/A3/T)
D18: U$2.18/A4 (18/A4/T/SDA0)
D19: U$2.19/A5 (19/A5/T/SCL0)
D20: U$2.20/A6 (20/A6/PWM)
D21: C7.2, U2.12 (XOUT), U$2.21/A7 (21/A7/PWM)
D22: C9.1, U2.10 (YOUT), U$2.22/A8 (22/A8/T/PWM)
D23: C8.1, U2.8 (ZOUT), U$2.23/A9 (23/A9/T/PWM)
GND: C1.2, C2.1, C3.2, C4.2, C5.1, C6.1, C7.1, C8.2, C9.2, C10.2, C12.1, C17.1, C19.2, C20.2, PAD1.1, PAD2.1, R1.1, SG1.- (2), SM24CANA.3 (C), U1.3, U1.6, U1.7, U2.3 (COM), U2.5 (COM), U2.6 (COM), U2.7 (COM), U$1.8 (GND), U$1.9 (GND_ANT), U$2.AGND, U$2.GND, U$3.1, VP230.2 (GND)
unnamed: C12.2, GF1A3.C, U1.1
unnamed: C19.1, GF1A4.C, U1.2
unnamed: R37.1, U1.4
unnamed: C20.1, U1.5
unnamed: R1.2, VP230.8 (RS)
unnamed: C3.1, R2.2, R3.1

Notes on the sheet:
CANBUS
CONNECTOR
NRF24L01 SMD PAD
3.3v REGULATOR

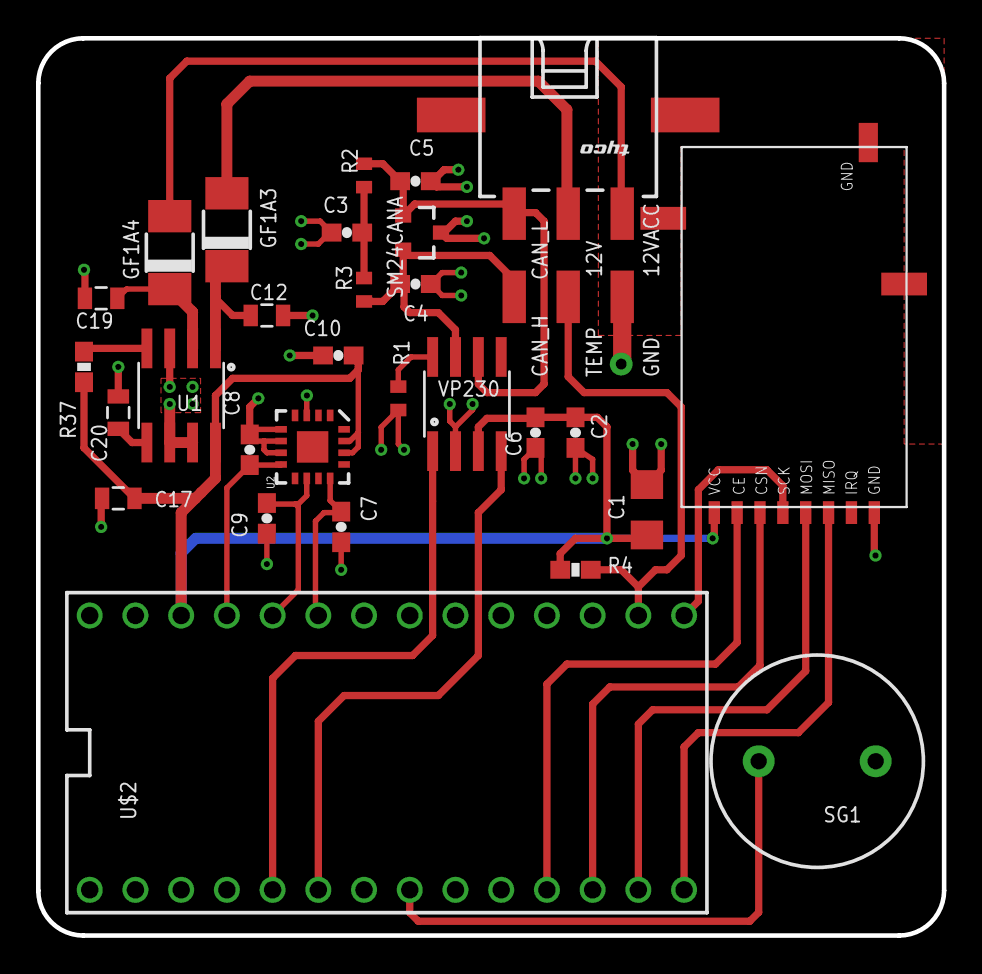
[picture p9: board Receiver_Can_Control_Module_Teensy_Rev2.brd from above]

Board: 2 copper layers, 50.3 x 49.8 mm, 31 parts (0 on the bottom side), 24 nets.

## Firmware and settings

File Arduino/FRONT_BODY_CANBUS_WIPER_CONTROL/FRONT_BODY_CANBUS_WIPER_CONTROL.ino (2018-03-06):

#include <Metro.h>
#include <FlexCAN.h>
#include <EEPROM.h>
#include <Bounce.h>
#include "Arduino.h"
#include "lin.h"

Metro cansend = Metro(20);// milliseconds

static CAN_message_t msg0;

#define RED 0x0
#define BLUE 0x1

#define interval 4000
#define send_interval 40

byte counter = 0x00; 
byte state = 0xdf;
byte sp = 0x00; 
int counter0 = 0;
unsigned long waitUntil = 0;

int hood = 5;
int brake = 0;

Lin lin;

int led0 = 20;
int led1 = 19;
int led2 = 18;
int led3 = 8;
int led4 = 21;
int led5 = 2;
int led6 = 1;
int led7 = 7;
int led8 = 22;
int led9 = 23;
int washer = 11;
int horn = 12;

int strobe_status=0;
static CAN_message_t rxmsg;

byte whichLED = RED;
byte Red_State = LOW;
byte Blue_State = LOW;

unsigned long switchDelay = 400;
unsigned long strobeDelay = 50;
unsigned long strobeWait = 0;
unsigned long waitUntilSwitch = 0;//(millis()-switchDelay);
// -------------------------------------------------------------
void setup(){
 Can0.begin(100000);
 lin.begin(19200);

 pinMode(led0, OUTPUT);
 pinMode(led1, OUTPUT);
 pinMode(led2, OUTPUT);
 pinMode(led3, OUTPUT);
 pinMode(led4, OUTPUT);
 pinMode(led5, OUTPUT);
 pinMode(led6, OUTPUT);
 pinMode(led7, OUTPUT);
 pinMode(led8, OUTPUT);
 pinMode(led9, OUTPUT);
 pinMode(horn, OUTPUT);
 pinMode(washer, OUTPUT);
 pinMode(hood,INPUT);
 pinMode(brake,INPUT);

 digitalWrite(led0, 0);
 digitalWrite(led1, 0);
 digitalWrite(led2, 0);
 digitalWrite(led3, 0);
 digitalWrite(led4, 0);
 digitalWrite(led5, 0);
 digitalWrite(led6, 0);
 digitalWrite(led7, 0);
 analogWrite(led8, 0);
 analogWrite(led9, 0);
 digitalWrite(horn, 0);
 digitalWrite(washer, 0);
 digitalWrite(hood,HIGH);
 digitalWrite(brake,HIGH);
}

//--------------------------------------------------------------

void sendstop ()
{
  if (counter0 == 0){
    uint8_t stop1[] = { 0x00, 0x00, 0x00, 0x00, 0x00, counter, 0x00, 0x00 };
    lin.send(0x47, stop1,8,2);
    if ((unsigned long)(millis() - waitUntil) >= send_interval) {
    lin.send(0x47, stop1,8,2);
    }
  }
   else{
    uint8_t stop1[] = { 0x1f, 0xef, 0xca, 0xff, 0x28, counter, 0x00, 0x00 };
    if ((unsigned long)(millis() - waitUntil) >= send_interval) {
    lin.send(0x47, stop1,8,2);
    counter0 = 1;
    }
   } 
}
//--------------------------------------------------------------

void sendspeed1 ()
{
 uint8_t speed1[] = { 0x3f, 0xef, 0xda, 0xff, 0x28, counter, 0x14, 0x00 }; 
 if ((unsigned long)(millis() - waitUntil) >= send_interval) {
 lin.send(0x47, speed1,8,2);
 } 
}

void sendspeed2 ()
{
 uint8_t speed2[] = { 0x3f, 0xef, 0xda, 0xff, 0x28, counter, 0x1c, 0x00 };
 if ((unsigned long)(millis() - waitUntil) >= send_interval) {
 lin.send(0x47, speed2,8,2);
 }
}
//--------------------------------------------------------------

void sendinterval1 ()
{ 
 uint8_t interval1[] = { 0x1f, 0xef, 0xca, 0xff, 0x28, counter, 0x00, 0x00 };
 if ((unsigned long)(millis() - waitUntil) >= send_interval) {
 lin.send(0x47, interval1,8,2);
 }
 if ((unsigned long)(millis() - waitUntil) >= interval) {
  uint8_t interval1[] = { 0x3f, 0xef, 0xda, 0xff, 0x28, counter, 0x14, 0x00 };
  if ((unsigned long)(millis() - waitUntil) >= send_interval) {
  lin.send(0x47, interval1,8,2);
  }
  if ((unsigned long)(millis() - waitUntil) >= send_interval) {
  lin.send(0x47, interval1,8,2);
  waitUntil = waitUntil + interval;
  }
 }
}
             
//--------------------------------------------------------
void loop(){
  
counter = counter + 0x10;
 if (counter == 0xf0)
 {
  counter = 0x00;
 }  

if ( Can0.read(rxmsg) ) {
       
      switch (rxmsg.id) { 
       case 150:

        
        //*******************************Turn/Hazard
        if (rxmsg.buf[0]==0){
        digitalWrite(led4,0);  
        digitalWrite(led5,0);
        digitalWrite(led6,0);  
        digitalWrite(led7,0);
      }
        if (rxmsg.buf[0]==1){
        digitalWrite(led4,0);  
        digitalWrite(led6,0);
        digitalWrite(led5,1);
        digitalWrite(led7,1);
      }
        if (rxmsg.buf[0]==2){  
        digitalWrite(led5,0);  
        digitalWrite(led7,0);
        digitalWrite(led4,1);
        digitalWrite(led6,1);
      }
        if (rxmsg.buf[0]==4){
        digitalWrite(led4,1);  
        digitalWrite(led5,1);
        digitalWrite(led7,1);
        digitalWrite(led6,1);
      }
      //*******************************DLR_1

        if (rxmsg.buf[1]==0){
        analogWrite(led8,0);          
      }
        if (rxmsg.buf[1]==1){
        analogWrite(led8,254);  
      }
        if (rxmsg.buf[1]==2){
        analogWrite(led8,20);  
      }

      //*******************************DLR_2

        if (rxmsg.buf[2]==0){
        analogWrite(led9,0);  
      }
        if (rxmsg.buf[2]==1){
        analogWrite(led9,254);  
      }
        if (rxmsg.buf[2]==2){
        analogWrite(led9,20);  
      }

      //*******************************Cruze Lights/LowBeam

        if (rxmsg.buf[4]==0){
        digitalWrite(led2,0);  
        digitalWrite(led3,0);
      }
        if (rxmsg.buf[4]==2){
        digitalWrite(led2,1);  
        digitalWrite(led3,1);
      }

      //*******************************HighBeam
        int hibeam_status =bitRead(rxmsg.buf[4],2);
        if (hibeam_status ==0){
        digitalWrite(led0,0);  
        digitalWrite(led1,0);
      }
        if (hibeam_status ==1){
        digitalWrite(led0,1);  
        digitalWrite(led1,1);
      }

     //*******************************Winshield
        int wiper_stop_speed1 = bitRead(rxmsg.buf[6],2);
        int wiper_speed2 = bitRead(rxmsg.buf[6],3);
        int wiper_interval=bitRead(rxmsg.buf[6],4);
        if ((wiper_stop_speed1 == 0)&&(wiper_speed2 == 0)&& (wiper_interval == 0))sendstop ();
        if (wiper_stop_speed1 == 1)sendspeed1 ();
        if (wiper_speed2 == 1)sendspeed2 ();
        if (wiper_interval == 1)sendinterval1 ();
      //*******************************Horn/Washer
        int horn_status=bitRead(rxmsg.buf[6],1);
        int washer_status=bitRead(rxmsg.buf[6],0);
        if (horn_status==0){
        digitalWrite(horn,0); 
      }
        if (washer_status==0){
        digitalWrite(washer,0); 
      }
        if (horn_status==1){
        digitalWrite(horn,1);  
      }
        if (washer_status==1){
        digitalWrite(washer,1); 
      }
      //*******************************Strobe
        strobe_status=bitRead(rxmsg.buf[3],1);
        if (strobe_status==1){
          strobe();
        }
      //*******************************
      break;
      }
    }

    int hood_status=!digitalRead(hood);
    int brake_status=!digitalRead(brake);

    if (cansend.check() == 1) {

    msg0.len = 8;
    msg0.id = 1976;
    msg0.buf[0] = hood_status;
    msg0.buf[1] = brake_status;
    msg0.buf[2] = 0;
    msg0.buf[3] = 0;
    msg0.buf[4] = 0;
    msg0.buf[5] = 0;
    msg0.buf[6] = 0;
    msg0.buf[7] = 0;
    Can0.write(msg0);
    }
}

// ------------------------------------------------------------- 

void strobe(){

  int StrobeFunction1=bitRead(rxmsg.buf[7],1);
  int StrobeFunction2=bitRead(rxmsg.buf[7],2);
  int StrobeFunction3=bitRead(rxmsg.buf[7],3);
  if(StrobeFunction1==1){
    digitalWrite(led8,0);
    digitalWrite(led9,0);
    digitalWrite(led6,Red_State);
    digitalWrite(led7,Blue_State);}

  if(StrobeFunction2==1){
    digitalWrite(led6,0);
    digitalWrite(led7,0);
    digitalWrite(led9,Red_State);
    digitalWrite(led8,Blue_State);
    }
     
  if(StrobeFunction3==1){
    digitalWrite(led6,Red_State);
    digitalWrite(led7,Blue_State);
    digitalWrite(led9,Red_State);
    digitalWrite(led8,Blue_State);}
    
  unsigned long waitUntilSwitch0 = millis(); 
    if(waitUntilSwitch0 - waitUntilSwitch > switchDelay) {
        waitUntilSwitch = waitUntilSwitch0;
        Red_State = 0;
        Blue_State = 0;
        whichLED = !whichLED;  // toggle LED to strobe
        //waitUntilSwitch += switchDelay;//switchDelay;
    }
 
    // Create the strobing effect
   unsigned long strobeWait0 = millis(); 
    if(strobeWait0 - strobeWait > strobeDelay) {
        strobeWait = strobeWait0;
       if (whichLED == RED)
       Red_State = !Red_State;
       if (whichLED == BLUE)
       Blue_State = !Blue_State;
    }
}

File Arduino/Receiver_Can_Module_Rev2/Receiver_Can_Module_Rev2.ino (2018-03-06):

#include <Metro.h>
#include <FlexCAN.h>
#include <SPI.h>
#include "nRF24L01.h"
#include "RF24.h"
#include <EEPROM.h>
#include "ClickButton.h"
#define RED 0x0
#define BLUE 0x1
#include "printf.h"

Metro cansend = Metro(20);// milliseconds

RF24 radio(9,10);
// Pins on the remote for buttons
const uint8_t num_button_pins = 10;
static CAN_message_t msg;
//static CAN_message_t msg0;
static CAN_message_t msg1;

struct payload_t
{
  uint16_t buttons;
};

uint8_t button_states[10];

const int buttons = 10;
int function[buttons] = {0, 0, 0, 0, 0, 0, 0, 0, 0, 0};

unsigned long waitUntil = 0;

int beep1_counter=0;
int beep2_counter=0;
int beep3_counter=0;
int beep4_counter=0;
int beep5_counter=0;
int beep6_counter=0;
int beep7_counter=0;
int beep8_counter=0;
int beep9_counter=0;
int beep10_counter=0;
int Hazard = 0;
int Strobe = 0;
int Rain = 0;
int Lturn = 0;
int Rturn = 0;
int DLR = EEPROM.read(0);
int StrobeFunction = EEPROM.read(1);
int Reverse = 0;
int Lights = 0;
int HighBeam = 0;
int Speed = 0;
int Windshield = 0;
int Horn = 0;
int Washer = 0;
int count = 0;
int wiper_funtion = 0;
int wiper_funtion1 = 0;
int wiper_funtion2 = 0;
int Lights_Radio=0;

const int buttonPin0=24;
const int buttonPin1=25;
const int buttonPin2=26;
const int buttonPin3=27;
const int buttonPin4=28;
const int buttonPin5=29;
const int buttonPin6=30;
const int buttonPin7=31;
const int buttonPin8=32;
const int buttonPin9=33;

unsigned char bit0;
unsigned char bit1;
unsigned char bit2;
unsigned char bit3;
unsigned char bit4;
unsigned char bit5;
unsigned char bit6;
unsigned char bit7;

ClickButton button[10] = {
ClickButton (buttonPin0, HIGH),
ClickButton (buttonPin1, HIGH),
ClickButton (buttonPin2, HIGH),
ClickButton (buttonPin3, HIGH),
ClickButton (buttonPin4, HIGH),
ClickButton (buttonPin5, HIGH),
ClickButton (buttonPin6, LOW),
ClickButton (buttonPin7, HIGH),
ClickButton (buttonPin8, HIGH),
ClickButton (buttonPin9, HIGH),
}; 
// -------------------------------------------------------------
void setup(){

  Can0.begin(100000);
  radio.begin();
  Serial.begin(9600);
  radio.setChannel(10);//0:steering.V1, 5:test_board.v1, 10:steering.V2
  radio.setDataRate(RF24_250KBPS);
  radio.setRetries(10,10);
  radio.openReadingPipe(1,0xE7E7E7E7E7LL);
  radio.startListening();

  for (int i=0; i<buttons; i++)
  { 
    // Setup button timers (all in milliseconds / ms)
    // (These are default if not set, but changeable for convenience)
    button[i].debounceTime   = 20;   // Debounce timer in ms
    button[i].multiclickTime = 250;  // Time limit for multi clicks
    button[i].longClickTime  = 1000; // Time until long clicks register
  }    
}
// -------------------------------------------------------------

void loop(){
    while (radio.available())
      {
        if ( radio.available() ) {
        radio.read( button_states, num_button_pins );
        //printf("Got buttons\n\r");
        }
      }
  
// -------------------------------------------------------------
    if (cansend.check() == 1) {
    msg.len = 8;
    msg.id = 150;
    msg.buf[0] = bit0;
    msg.buf[1] = bit1;
    msg.buf[2] = bit2;
    msg.buf[3] = bit3;
    msg.buf[4] = bit4;
    msg.buf[5] = bit5;
    msg.buf[6] = bit6;
    msg.buf[7] = bit7;
    Can0.write(msg); 

    msg1.len = 8;
    msg1.id = 1589;
    msg1.buf[0] = Lights_Radio;
    msg1.buf[1] = 0;
    msg1.buf[2] = 0;
    msg1.buf[3] = 0;
    msg1.buf[4] = 0;
    msg1.buf[5] = 0;
    msg1.buf[6] = 0;
    msg1.buf[7] = 0;
    Can0.write(msg1);
    }
    
// -------------------------------------------------------------
  for (int i=0; i<10; i++)
  {
  button[i].buttonState = button_states[i];
  button[i].Update();
  if (button[i].clicks != 0) function[i] = button[i].clicks;
  }
// -------------------------------------------------------------L-Turn

  if(button[8].clicks == 1) Lturn = !Lturn;
  if(Lturn == 1){
    Rturn = 0; 
    lturn();
  }
// -------------------------------------------------------------R-Turn

  if(button[7].clicks == 1) Rturn = !Rturn;
  if(Rturn == 1){
    Lturn =0;
    rturn();
  }
// -------------------------------------------------------------Hazard
  int rain_status,strobe_status;
  if(button[2].clicks == 1) Hazard = !Hazard;
  if(Hazard == 1){
    Lturn = 0;
    Rturn = 0;
    hazard();
  }
  if((Lturn == 0) && (Rturn == 0) && (Hazard == 0)) {
    beep1_counter = 0;
    beep2_counter = 0;
    bit0=0;
    //noTone(6); 
  }
  if(button[2].clicks == 2) Rain = !Rain;
  if(Rain == 1) rain_status=1;
  if(Rain == 0) rain_status=0;
  if(button[2].clicks == -1) Strobe = !Strobe;
  if(Strobe == 0){
    strobe_status=0;
  }
  if(Strobe == 1){
    Lturn = 0;
    Rturn = 0;
    Hazard = 0;
    Lights = 0;
    bit1=0;
    bit2=0;
    strobe_status=2;
  }
  if(strobe_status == 2){
    beep3_counter = beep3_counter+1;
    beep4_counter = 0;
    if(beep3_counter < 15000)tone(6, 3000);
    if(beep3_counter == 15000)noTone(6);
  }
  if(strobe_status == 0){
    beep4_counter = beep4_counter+1;
    beep3_counter = 0;
    if(beep4_counter < 15000)tone(6, 3000);
    if(beep4_counter == 15000)noTone(6);
  }
  bit3=rain_status+strobe_status;

//--------------------------------------------------------------DLR

       if ((Lturn==0)&&(Hazard==0)&&(Lights==0)&&(Reverse==0)&&(DLR==1)&&(Strobe==0)){bit2=1;}
       else{if ((Lturn!=0)||(Hazard!=0)||(DLR==0)){if((Reverse==0)&&(Strobe==0)){bit2=0;}}}
         
       if ((Rturn==0)&&(Hazard==0)&&(Lights==0)&&(Reverse==0)&&(DLR==1)&&(Strobe==0)){bit1=1;}
       else{if ((Rturn!=0)||(Hazard!=0)||(DLR==0)){if((Reverse==0)&&(Strobe==0)){bit1=0;}}} 
        
// -------------------------------------------------------------Lights
int bit4state;
if(button[1].clicks == 1) Lights = Lights+1;
if(Lights==1){
  Lights_Radio=1;
  if((Lturn==0)&&(Hazard==0)){DLR2();}
  if((Rturn==0)&&(Hazard==0)){DLR1();}
  bit4state=1;
  bit4=bit4state;
  HighBeam=0;}

if(Lights==2){
  Lights_Radio=1;
  if((Lturn==0)&&(Hazard==0)){DLR2();}
  if((Rturn==0)&&(Hazard==0)){DLR1();}
  bit4state=2;
  bit4=bit4state;}

  if(Lights==3) Lights=0;
  if(Lights==0){
    Lights_Radio=0;
    bit4state=0;
    bit4=bit4state;
    HighBeam=0;
   }

if(button[1].clicks == -1)DLR = !DLR; 
EEPROM.write(0,DLR);

if(DLR == 1){
    beep5_counter = beep5_counter+1;
    beep6_counter = 0;
    if(beep5_counter < 15000)tone(6, 3000);
    if(beep5_counter == 15000)noTone(6);
  }
  if(DLR == 0){
    beep6_counter = beep6_counter+1;
    beep5_counter = 0;
    if(beep6_counter < 15000)tone(6, 3000);
    if(beep6_counter == 15000)noTone(6);
  }

if(button[1].clicks == 2)StrobeFunction = StrobeFunction + 1;
  if(StrobeFunction >= 3)StrobeFunction=0;
EEPROM.write(1,StrobeFunction);
  if(StrobeFunction==0)bit7=2;
  if(StrobeFunction==1)bit7=4;
  if(StrobeFunction==2)bit7=8;

// -------------------------------------------------------------HighBeam

int HighBeam_states;
if(button_states[0] == 0)HighBeam_states =0;
if(button_states[0] == 1)HighBeam_states =4;
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

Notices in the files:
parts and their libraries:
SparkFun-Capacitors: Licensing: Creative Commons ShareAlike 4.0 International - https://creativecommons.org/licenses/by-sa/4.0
